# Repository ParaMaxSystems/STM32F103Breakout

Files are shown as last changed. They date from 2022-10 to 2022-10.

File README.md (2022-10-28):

# STM32F103Breakout
STM32 Breakout Board with Power Stage, inspired by Phil's Lab's design. 
STM32F103C8T board with connectors for I2C, USB, SPI, and GPIO headers.
Broken out to fit vertical or horizontal connectors.
Powered by a 3.3v switching regulator, taking power from USB or Vin and
conrverting to a 3.3v power source. Can be much smaller but I don't want to.

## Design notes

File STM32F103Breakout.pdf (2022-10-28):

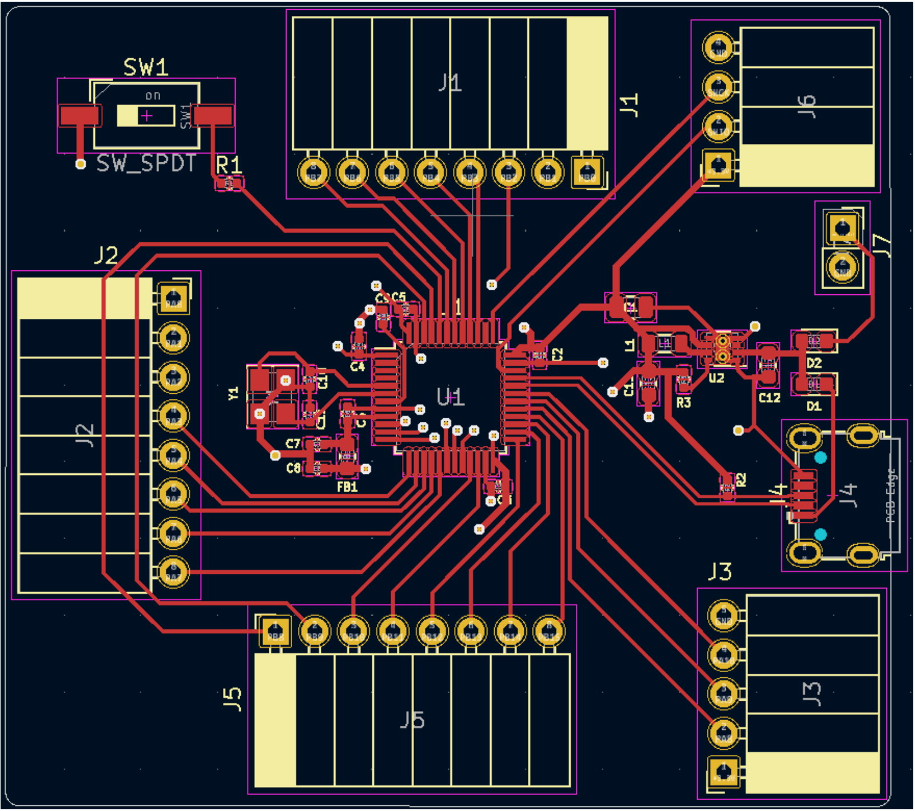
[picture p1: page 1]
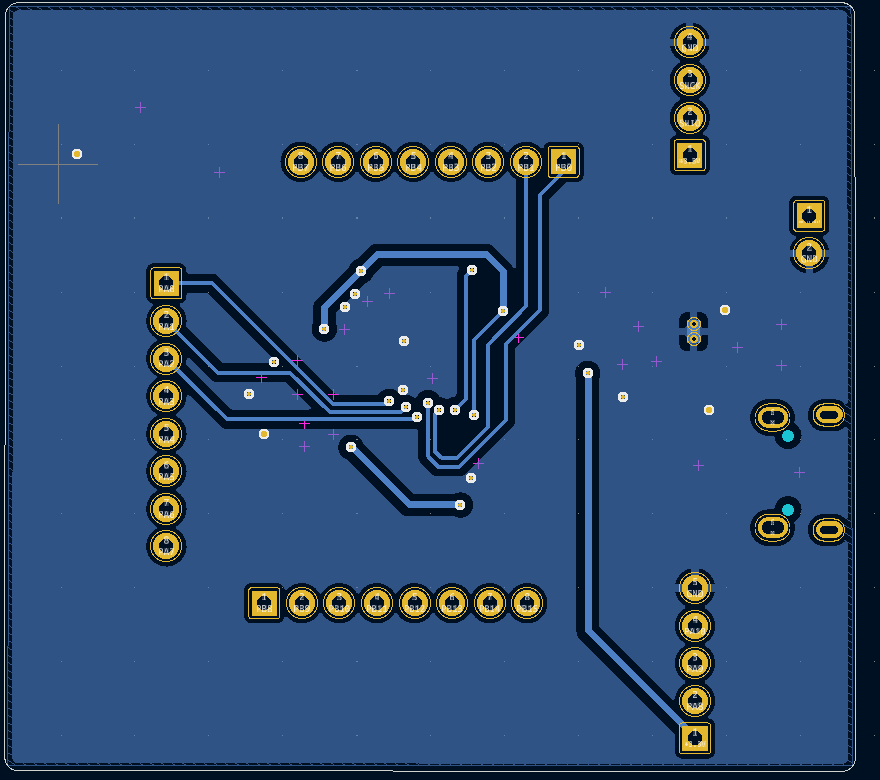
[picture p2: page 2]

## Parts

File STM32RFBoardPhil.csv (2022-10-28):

Designator | Comment | Footprint
C1 | 10u | Capacitor_SMD:C_0805_2012Metric
C2 | 100n | Capacitor_SMD:C_0402_1005Metric
C3 | 100n | Capacitor_SMD:C_0402_1005Metric
C4 | 100n | Capacitor_SMD:C_0402_1005Metric
C5 | 100n | Capacitor_SMD:C_0402_1005Metric
C6 | 10n | Capacitor_SMD:C_0402_1005Metric
C7 | 1u | Capacitor_SMD:C_0402_1005Metric
C8 | 1u | Capacitor_SMD:C_0402_1005Metric
C9 | 100n | Capacitor_SMD:C_0402_1005Metric
C10 | 10p | Capacitor_SMD:C_0402_1005Metric
C11 | 10p | Capacitor_SMD:C_0402_1005Metric
C12 | 10u | Capacitor_SMD:C_0603_1608Metric
C13 | 22u | Capacitor_SMD:C_0603_1608Metric
D1 | DIODE | Diode_SMD:D_0603_1608Metric
D2 | DIODE | Diode_SMD:D_0603_1608Metric
FB1 | 120R@100MHz | Inductor_SMD:L_0603_1608Metric
J1 | Conn_01x08_Female | Connector_PinSocket_2.54mm:PinSocket_1x08_P2.54mm_Horizontal
J2 | Conn_01x08_Female | Connector_PinSocket_2.54mm:PinSocket_1x08_P2.54mm_Horizontal
J3 | Conn_01x05_Female | Connector_PinSocket_2.54mm:PinSocket_1x05_P2.54mm_Horizontal
J4 | USB_B_Micro | Connector_USB:USB_Micro-B_Wuerth_629105150521
J5 | Conn_01x08_Female | Connector_PinSocket_2.54mm:PinSocket_1x08_P2.54mm_Horizontal
J6 | Conn_01x04_Female | Connector_PinSocket_2.54mm:PinSocket_1x04_P2.54mm_Horizontal
J7 | Conn_01x02_Female | Connector_PinSocket_2.54mm:PinSocket_1x02_P2.54mm_Vertical
L1 | 4.7u | Inductor_SMD:L_0805_2012Metric
R1 | 10k | Resistor_SMD:R_0402_1005Metric
R2 | 10k | Resistor_SMD:R_0402_1005Metric
R3 | 100k | Resistor_SMD:R_0402_1005Metric
SW1 | SW_SPDT | Button_Switch_SMD:SW_DIP_SPSTx01_Slide_6.7x4.1mm_W8.61mm_P2.54mm_LowProfile
U1 | STM32F103C8Tx | Package_QFP:LQFP-48_7x7mm_P0.5mm
U2 | TPS62162DSG | Package_SON:WSON-8-1EP_2x2mm_P0.5mm_EP0.9x1.6mm_ThermalVias
Y1 | Crystal_GND24_Small | Crystal:Crystal_SMD_3225-4Pin_3.2x2.5mm

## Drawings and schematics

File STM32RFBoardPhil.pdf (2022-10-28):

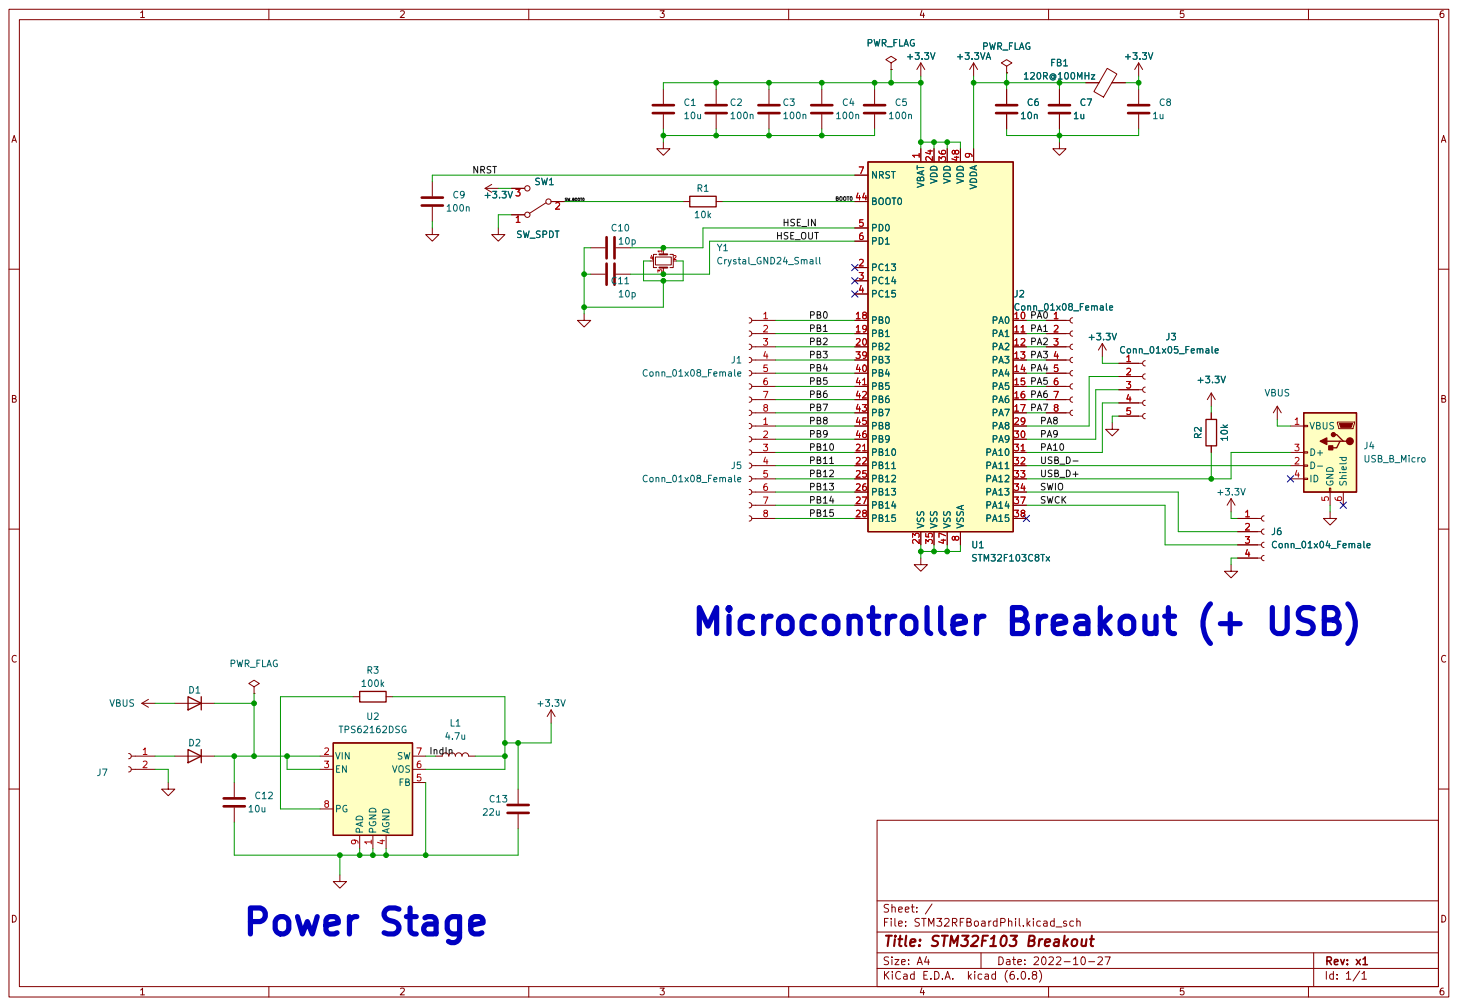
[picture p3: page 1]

1 PA0 10 PA1 11 PA2 12 PA3 13 PA4 14 PA5 15 PA6 16 PA7 17 PB0 18 PB1 19 PC13 2 PB2 20 PB10 21 PB11 22 VSS 23 VDD 24 PB12 25 PB13 26 PB14 27 PB15 28 PA8 29 PC14 3 PA9 30 PA10 31 PA11 32 PA12 33 PA13 34 VSS 35 VDD 36 PA14 37 PA15 38 PB3 39 PC15 4 PB4 40 PB5 41 PB6 42 PB7 43 BOOT0 44 PB8 45 PB9 46 VSS 47 VDD 48 PD0 5 PD1 6 NRST 7 VSSA

4 FB 5 VOS 6 SW 7 PG 8 PAD

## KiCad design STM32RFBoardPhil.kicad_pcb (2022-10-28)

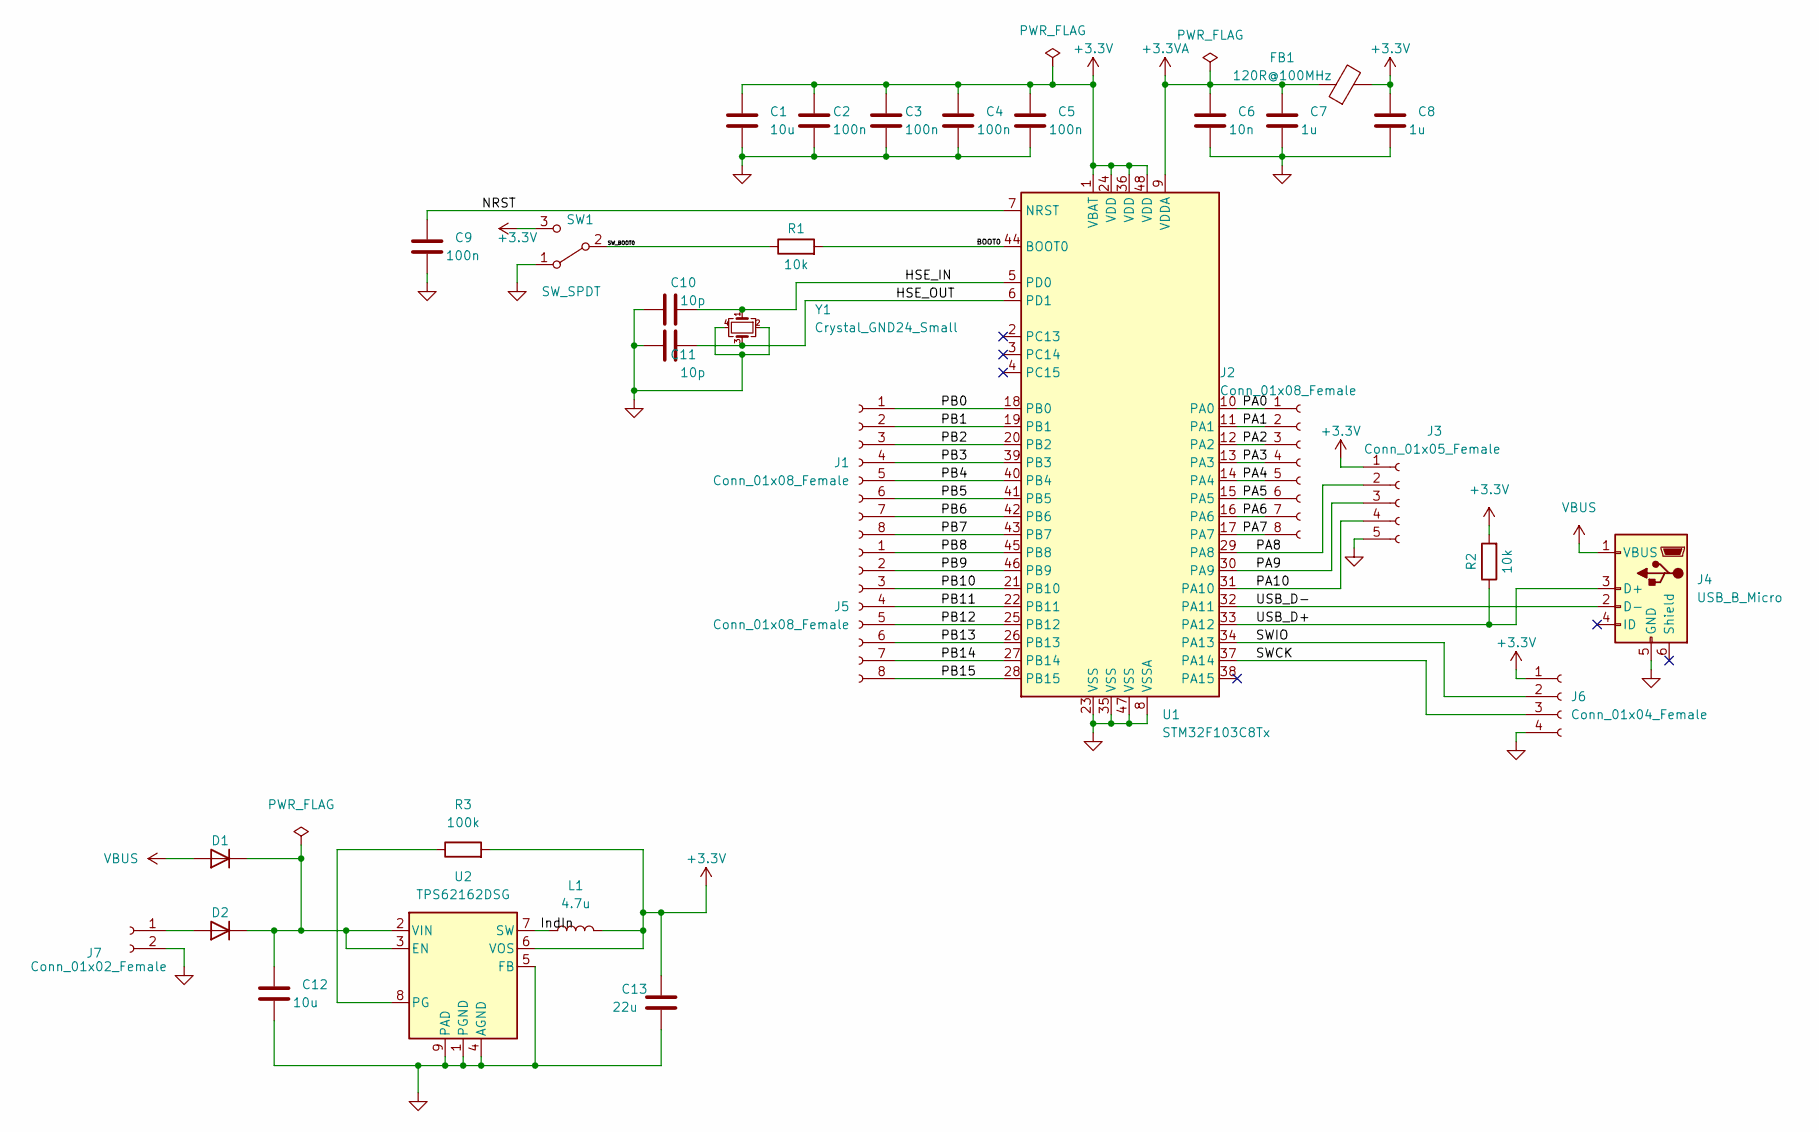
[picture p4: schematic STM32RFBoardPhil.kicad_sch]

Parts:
C1: 10u; C_0805_2012Metric
C2, C3, C4, C5, C9: 100n; C_0402_1005Metric
C6: 10n; C_0402_1005Metric
C7, C8: 1u; C_0402_1005Metric
C10, C11: 10p; C_0402_1005Metric
C12: 10u; C_0603_1608Metric
C13: 22u; C_0603_1608Metric
D1, D2: DIODE; D_0603_1608Metric
FB1: 120R@100MHz; L_0603_1608Metric
J1, J2, J5: Conn_01x08_Female; PinSocket_1x08_P2.54mm_Horizontal
J3: Conn_01x05_Female; PinSocket_1x05_P2.54mm_Horizontal
J4: USB_B_Micro; USB_Micro-B_Wuerth_629105150521
J6: Conn_01x04_Female; PinSocket_1x04_P2.54mm_Horizontal
J7: Conn_01x02_Female; PinSocket_1x02_P2.54mm_Vertical
L1: 4.7u; L_0805_2012Metric
R1, R2: 10k; R_0402_1005Metric
R3: 100k; R_0402_1005Metric
SW1: SW_SPDT; SW_SPDT_CK-JS102011SAQN
U1: STM32F103C8Tx; LQFP-48_7x7mm_P0.5mm
U2: TPS62162DSG; WSON-8-1EP_2x2mm_P0.5mm_EP0.9x1.6mm_ThermalVias
Y1: Crystal_GND24_Small; Crystal_SMD_3225-4Pin_3.2x2.5mm

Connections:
+3.3V: C1.1, C2.1, C3.1, C4.1, C5.1, C8.1, C13.1, FB1.2, J3.1, J6.1, L1.2, R2.2, R3.2, SW1.3 (C), U1.1 (VBAT), U1.24 (VDD), U1.36 (VDD), U1.48 (VDD), U2.6 (VOS)
+3.3VA: C6.1, C7.1, FB1.1, U1.9 (VDDA)
/BOOT0: R1.2, U1.44 (BOOT0)
/HSE_IN: C10.2, U1.5 (PD0), Y1.1
/HSE_OUT: C11.2, U1.6 (PD1), Y1.3
/IndIn: L1.1, U2.7 (SW)
/NRST: C9.1, U1.7 (NRST)
/PA0: J2.1, U1.10 (PA0)
/PA1: J2.2, U1.11 (PA1)
/PA2: J2.3, U1.12 (PA2)
/PA3: J2.4, U1.13 (PA3)
/PA4: J2.5, U1.14 (PA4)
/PA5: J2.6, U1.15 (PA5)
/PA6: J2.7, U1.16 (PA6)
/PA7: J2.8, U1.17 (PA7)
/PA8: J3.2, U1.29 (PA8)
/PA9: J3.3, U1.30 (PA9)
/PA10: J3.4, U1.31 (PA10)
/PB0: J1.1, U1.18 (PB0)
/PB1: J1.2, U1.19 (PB1)
/PB2: J1.3, U1.20 (PB2)
/PB3: J1.4, U1.39 (PB3)
/PB4: J1.5, U1.40 (PB4)
/PB5: J1.6, U1.41 (PB5)
/PB6: J1.7, U1.42 (PB6)
/PB7: J1.8, U1.43 (PB7)
/PB8: J5.1, U1.45 (PB8)
/PB9: J5.2, U1.46 (PB9)
/PB10: J5.3, U1.21 (PB10)
/PB11: J5.4, U1.22 (PB11)
/PB12: J5.5, U1.25 (PB12)
/PB13: J5.6, U1.26 (PB13)
/PB14: J5.7, U1.27 (PB14)
/PB15: J5.8, U1.28 (PB15)
/SWCK: J6.3, U1.37 (PA14)
/SWIO: J6.2, U1.34 (PA13)
/SW_BOOT0: R1.1, SW1.2 (B)
/USB_D+: J4.3 (D+), R2.1, U1.33 (PA12)
/USB_D-: J4.2 (D-), U1.32 (PA11)
GND: C1.2, C2.2, C3.2, C4.2, C5.2, C6.2, C7.2, C8.2, C9.2, C10.1, C11.1, C12.2, C13.2, J3.5, J4.5 (GND), J6.4, J7.2, SW1.1 (A), U1.8 (VSSA), U1.23 (VSS), U1.35 (VSS), U1.47 (VSS), U2.1 (PGND), U2.4 (AGND), U2.5 (FB), U2.9 (PAD), Y1.2, Y1.4
unnamed: D2.1 (A), J7.1
unnamed: R3.1, U2.8 (PG)
unnamed: C12.1, D1.2 (K), D2.2 (K), U2.2 (VIN), U2.3 (EN)
VBUS: D1.1 (A), J4.1 (VBUS)

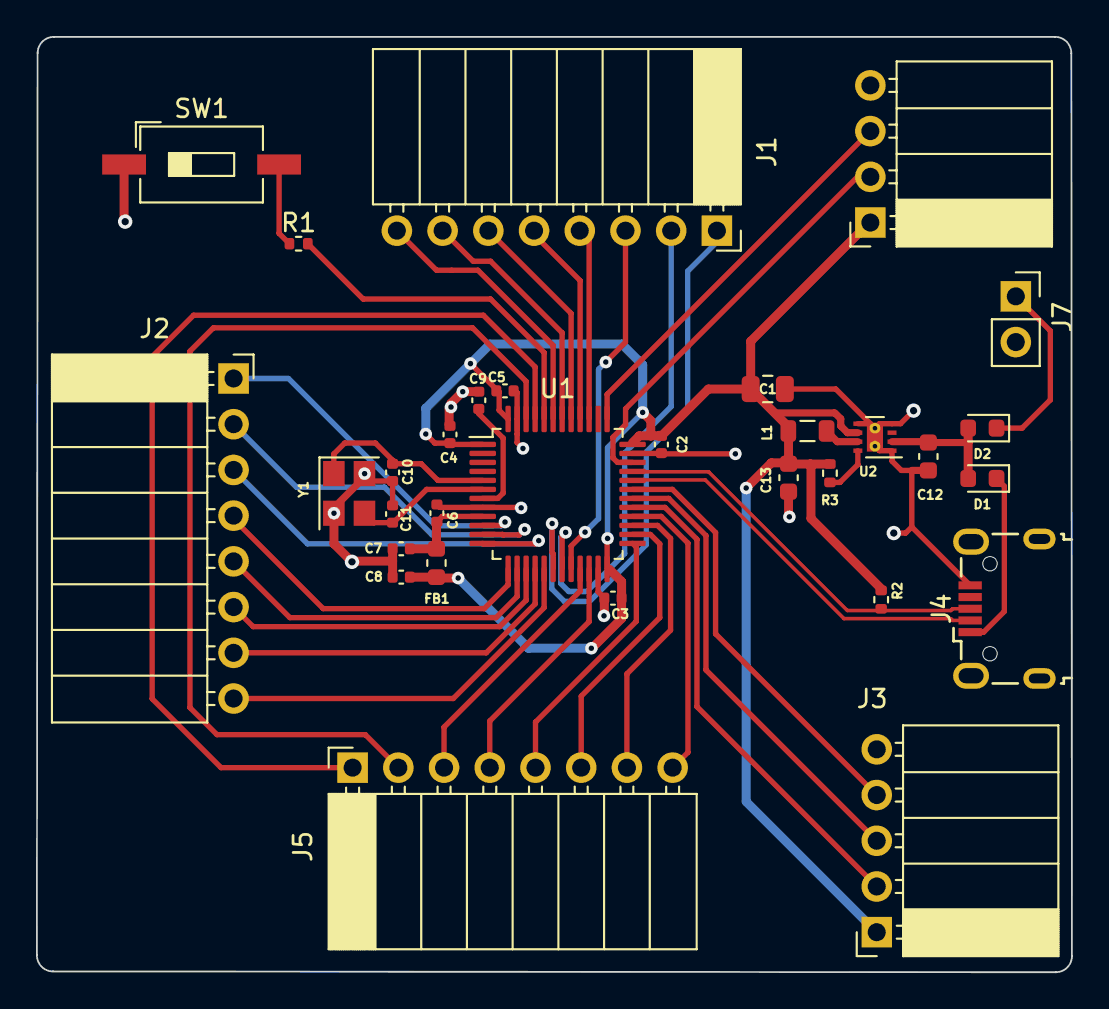
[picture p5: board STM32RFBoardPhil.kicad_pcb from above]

Board: 2 copper layers, 57.5 x 52.0 mm, 31 parts (0 on the bottom side), 44 nets.

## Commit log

2022-10-28 Dropped the stuff
    [STM32RFBoardPhil.csv, STM32RFBoardPhil.kicad_pcb, STM32RFBoardPhil.kicad_sch]
2022-10-28 Uploaded GERBERS
    [STM32RFBoardPhil-B_Cu.gbr, STM32RFBoardPhil-B_Mask.gbr, STM32RFBoardPhil-B_Paste.gbr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]
